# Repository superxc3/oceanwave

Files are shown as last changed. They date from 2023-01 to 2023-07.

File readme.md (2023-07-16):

# Oceanwave


Oceanwave is an ergonomic unibody keyboard with 3x6 column staggered keys and 3 thumb keys designed by XCMKB. Oceanwave was inspired by [Reviung41](https://github.com/gtips/reviung/tree/master/reviung41) and [Corne](https://github.com/foostan/crkbd) additional thumb key, splayed [Architeuthis Dux](https://github.com/tapioki/cephalopoda/tree/main/Architeuthis%20dux) with mx spacing. 

## Features
1. Hotswap for MX and Low Profile Choc (v1)
2. 8 RGB LED underglow 
3. 1 MX hotswap in the middle for Artisan. 
4. 1 flat wheel encoder
5. 1 EC11 / EC12 rotary encoder
6. 1 OLED
7. Pimoroni Haptic BZZZ DRV2605L Linear Actuator Haptic Breakout
8. Firmware supports wired VIAL and wireless ZMK
9. Modification of promicro or nicenano v2 for additional IOs. 
10. Power button for wireless build

## Versions
Supports multiple options of featuers for default micro controller
| Version | Features | Firmware | Wired | Wireless |
|:---|:---|:--:|:--:|:--:|
| Wirelss minimal | Flat wheel and knob | ZMK | | Yes |
| 2E | Flat wheel and knob | QMK/VIAL | Yes ||
| Oled 1E | Flat wheel or knob, Oled | QMK/VIAL | Yes ||
| Haptic 1E | Flat wheel or knob, Haptic BZZZ | QMK/VIAL | Yes ||

IO can be expanded by modifying the usb c promicro, inspired from [GOLEM](https://golem.hu/guide/pro-micro-upgrade/).
| Version | Features | Firmware | Wired | Wireless |
|:---|:---|:--:|:--:|:--:|
| Oled 2E* | Flat wheel and knob, Oled | QMK/VIAL | Yes ||
| Haptic 2E* | Flat wheel and knob, Haptic BZZZ | QMK/VIAL | Yes ||


Haptic Bzzz can always be added. Dang for the socketed haptic bzzz as well. 

## Build guide
[Refer here](https://github.com/superxc3/oceanwave/blob/main/build%20guide.md).

## Firmware
[Refer here](https://github.com/superxc3/oceanwave/tree/main/firmware)

## EC11/EC12 Encoders
1. EC11 is the typical 15mm rotary encoder used for most of the mx boards, the height is almost similar to mt3. 
2. EC12 is a relatively lower height rotary encoder, used for choc board to achieve thin board thickness.  

## OLED
oled

## Keyboard Images






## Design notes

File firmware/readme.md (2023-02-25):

# Firmware
Pre-assembled board is pre-flashed. Build kit please refer to [Ready-to-flash](https://github.com/superxc3/oceanwave/tree/main/firmware/ready-to-flash-firmware). If you wish to improve the codes, you will have to set up VIAL environment.

For pre-assembled and pre-flashed board, please download [VIAL](https://get.vial.today/download/) software to remap key. The software supports windows, mac, and linux. Basic layering and tapping guide refer [here](https://github.com/superxc3/xcmkb/blob/main/list%20of%20guide/vial-guide.md#basic-tapping-and-layering).

||
|:--:|
|Vial software interface|

## Wired QMK VIAL
- For usb-c promicro using caterina, copy xcmkb/oceanwave folder, make using `qmk compile -kb xcmkb/oceanwave -km vial`
- For rp2040 promicro, copy [oceanwave](https://drive.google.com/drive/folders/15KPRZ52J217cfi-xYsaPOL3EPukIM2lr?usp=sharing) folder to your qmk directory, make using `qmk compile -kb oceanwave -km vialoh2e`. Default uf2 which enabled all features download from [here](https://drive.google.com/file/d/1fGqhYeTPkiZEdB_yfewdT_9bDBihB43H/view?usp=share_link). 

### Configuration on Sparkfun RP2040 promicro
- Haptic vibration refers to [DRV2605L waveform library](https://github.com/qmk/qmk_firmware/blob/master/docs/feature_haptic_feedback.md#drv2605l-waveform-library); layers and tab key are added in the firmware, the rest just follow the template set in `haptic.c`.

## Wireless ZMK
Copy [oceanwave](https://drive.google.com/drive/folders/1NOylumwA9jJXKU2bHk5CELzXyPIMklsh?usp=share_link) to shields, this supports zmk-ftc only. Make using `west build -p -b nice_nano_v2 -- -DSHIELD=oceanwave`. Default keymap using reviung41 by adding extra key near to thumb. Default uf2 copy from [here](https://drive.google.com/file/d/1I9lbSuJ4-EFsmNMYBPXVArRPtXQpIEmn/view?usp=share_link). 
- no oled
- two encoders (flat wheel and rotary encoder)
- rgb included
- no haptic bzzz

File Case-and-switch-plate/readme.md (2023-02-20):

# Case and Switch Plate

## 3D case for plateless build 
This is suitable for low profile choc version without any switch plate, download [here](https://github.com/superxc3/oceanwave/blob/main/Case-and-switch-plate/Flat%20oceanwave2%20only%20-%20final%20touch.stl). 



o

3D reduces the overall thickness by 1mm compared to acrylic bottom, gap between bottom case and pcb are 2mm for 3D and 3mm for acrylic bottom.
- m2 x3mm screw at bottom
- m3 x3mm brass standsoff
- plastic washer on top of pcb
- m2 x3mm screw on top of pcb

### MCU cover
- m2 x3mm screw at bottom pcb
- m3 x11mm brass standsoff
- m2 x3mm screw on top of mcu cover

## Acrylic bottom plate
The gap between bottom acrylic plate and pcb is 3mm.
- m2 x3mm screw at bottom
- m3 x3mm brass standsoff
- m2 x3mm screw on top of pcb

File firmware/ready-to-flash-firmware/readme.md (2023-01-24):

# Ready to flash firmware

## Hex for caterina promicro
Using QMK Toolbox and refer [Tutorial to flash hex file](https://github.com/superxc3/xcmkb/blob/main/list%20of%20guide/flashing%20hex.md)

## uf2 for rp2040 
Flash before soldering. Connect usb c to pc.
1. Hold the boot button on mcu, double press reset button twice. 
2. A new window pop out.
3. Drop the uf2 to the folder.
4. Done.

## Version

### Default features
- 7 layers (Layer 0123456)
- 1000Hz polling rate
- OLED/haptic depends on the build
- Mousekey availability depends on firmware size
- RGB underglow effects number depends on firmware size
- super alt tab enabled to cycle between different windows (check User tab in vial)



### Oled2e
This version for OLED, without Haptic Bzzz, supports both knob and flat wheel encoders. Hex file download [here](https://drive.google.com/file/d/1fGqhYeTPkiZEdB_yfewdT_9bDBihB43H/view?usp=share_link). QMK VIAL firmware source code download [here](https://drive.google.com/drive/folders/1AIHQoCwNvRf_bx6QMLS1yq8Js87rkkeG?usp=share_link). 

Copy XCMKB and compile using `qmk compile -kb xcmkb/oceanwave -km vialoled2e`. Default comes with OLED indicator for layer, numlock, capslock, scrollock. Change the build option in oled.c for QMK logo. Animated oceanwave logo needs debug. 

**Optional features**
- mousekey disabled to accommodate rgb underglow
- qmk settings, combo, tap dance are disabled

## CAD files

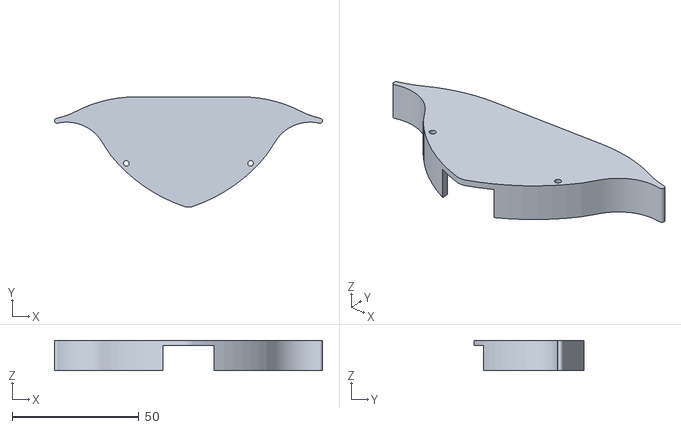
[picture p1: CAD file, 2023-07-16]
Case-and-switch-plate/mcu cover with 103040 1500mah battery.stl
105.9 x 43.6 x 12.0

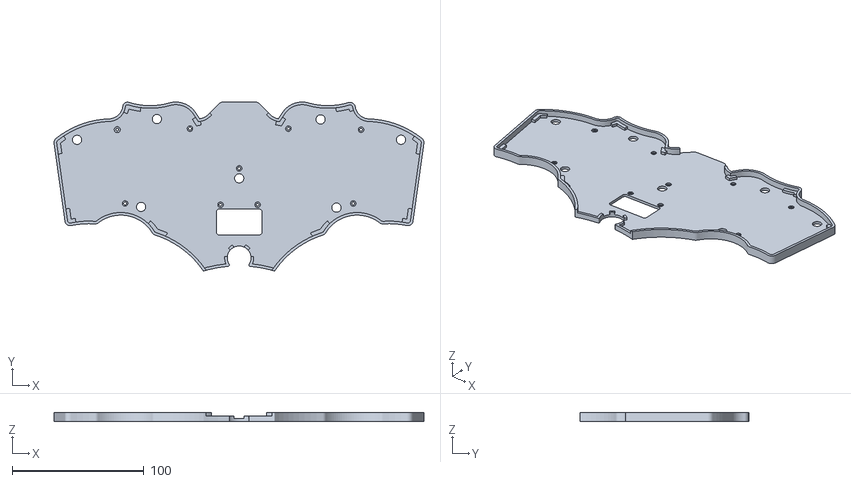
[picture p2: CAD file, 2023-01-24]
Case-and-switch-plate/Flat oceanwave2 only - final touch.stl
280.3 x 128.1 x 6.60

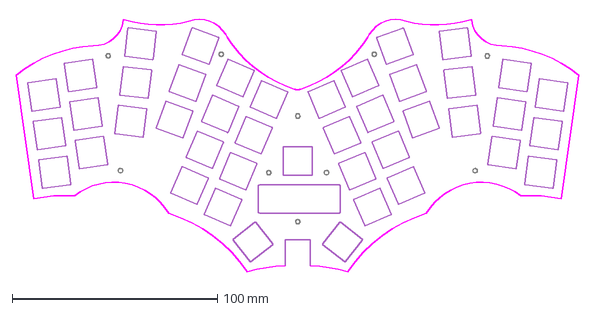
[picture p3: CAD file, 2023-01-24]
Case-and-switch-plate/Switch plate.dxf
274.1 x 124.4 mm

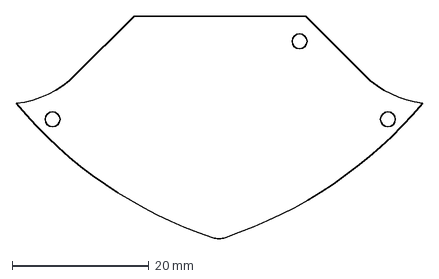
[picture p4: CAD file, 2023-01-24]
Case-and-switch-plate/MCU Cover.dxf
59.5 x 32.6 mm

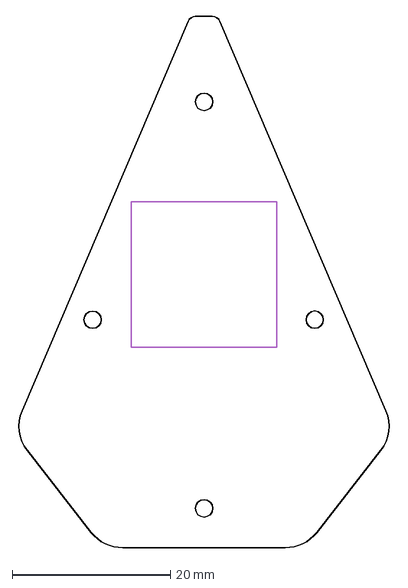
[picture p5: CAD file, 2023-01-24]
Case-and-switch-plate/Oled Cover.dxf
47.5 x 67.3 mm

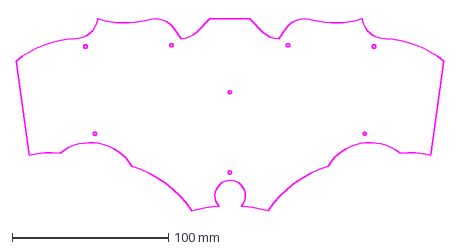
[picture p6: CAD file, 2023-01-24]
Case-and-switch-plate/Bottom Acrylic Plate without haptic.dxf
274.1 x 124.4 mm

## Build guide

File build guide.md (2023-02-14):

# Build Guide of Oceanwave

### Default combination
Due to limitation of IOs, not all features can be included (4. to 7.). Below shows the combination without modifying promicro / nicenano v2

1. 1 Flat Wheel Encoder + OLED  	(join split paste for OLED on top of PCB)
2. 1 Flat Wheel Encoder + BZZZ  	(join split paste for BZZZ on top of PCB)
2. 2 Encoders, no OLED and BZZZ 	(join split paste above the flat wheel on top of PCB)

:warning: Notes

1. If do not want flat wheel as first encoder and choose ec11 rotary encoder knob, join split paste at the bottom of PCB written "JOIN IF OMIT FLAT WHEEL"
2. Once flat wheel is soldered, it must be used.
3. DO NOT SIMPLY JOIN ANYTHING IF YOU DONT USE THAT FEATURE

### Additional combination
Below shows possible combination by jump wire certain spots for additional IOs.

#### 2 Encoders + OLED or BZZZ
1. Join the ENCC and D on top of mcu (bridge wire between IO and both points)
2. Do not join split paste above the flat wheel
3. Join split paste of OLED or BZZZ depends on your choice, do not join both.

:warning: Below will lead to conflict if
1. Join OLED or BZZZ and join split paste above the flat wheel
2. Join both OLED and BZZZ

## Basic build guide

### Diodes
There are two types of diodes for oceanwave. The top facing upwards is through-hole diode; while the bottom is using SMD diode. You have to solder both types of diodes. Follow the line indicated on the pcb. 

||
|:--:|
| Through-hole diode |

||
|:--:|
| SMD diode; refer to [DIODES](https://github.com/GEIGEIGEIST/KLOR/blob/main/docs/buildguide_3DP.md#diodes) for tips to solder SMD diode |

### MCU - Microcontroller and Reset Button
The build kit comes with socket for MCU. Solder the socket and reset button after diodes. Use tape to fix the socket and solder accordingly. Default comes with usb c promicro. 

||
|:--:|
|MCU and reset button |

||
|:--:|
| Insert the 3 pieces of 4pins at each side, put the mcu on top. Press while solder four sides of MCU, make sure no gap in between the mcu and pins. Continue to solder with the rest.|

### RGB Underglow
Apply some solder on one of the pads. Place the LED with tweezer according to the silk screen. Reheat the solder and apply some pressure with tweezer to make sure the LED is fully seated. There is an LED facing up in the middle for artisan purpose. Recommended not installed for OLED user (the led shines the oled component); and not recommended if you are not planning to insert any switch, it glares. 

||
|:--:|
|Indicator silk screen. The orientation is very important. |

### Switch Sockets
Apply some solder on one of the pads, then place the switch socket and reheat the solder. While heating, press the socket with finger or tweezer. Make sure the socket is fully seated, lift your soldering iron but make sure your finger or tweezer is still pressing the socket for 1-2s. Check if the socket is aligned, then only solder the second pad. Build guide for socket and refer to [Switch Sockets](https://github.com/GEIGEIGEIST/KLOR/blob/main/docs/buildguide_3DP.md#switch-sockets).

### Encoders

#### EC11 Knob only
If you only have one encoder and prefer ec11 knob rather than flat wheel, bridge the three jumpers near to L4 RGB underglow led, above flat wheel. 

||
|:--:|
| Join if omit flat wheel as the encoder|

||
|:--:|
|Top: EC12 encoder with lower height, suitable for low profile choc; |
|Bottom: EC11 encoder suitable for mx choc, the height of EC11 knob is similar to the the height of MT3 keycaps.|

  :warning: The EC11 encoder allows Mill-Max 0305. However, it appears to be less stable if using Mill-Max

#### EC11 Knob and Flat Wheel
If your configuration allows you to build two encoders (both flat wheel and ec11 knob), bridge the three jumpers above the knob.

  :rotating_light: Do not bridge three jumpers above the knob to enable the knob, bridge only if you have two encoders.

||
|:--:|
| Join if your config allows for two encoders|

#### EC11 Knob and Flat Wheel with Oled and Haptic Bzzz
All enabled by expanding IO for second encoder. 
||
|:--:|
| Join either one of the GND, top or bottom; the another two needs to be handwired |

### OLED and Haptic Bzzz
~~Choose only OLED or Haptic Bzzz. You are allowed to bridge one of them only because they shared the same pins.~~
OLED and Haptic Bzzz are both supported as long as your firmware can fit in. 
||
|:--:|
| Join the left 4 jumpers if choose for OLED; join the right 4 jumpers if choose for haptic bzzz. Socket for OLED on top; socket for haptic at the bottom. The photo above shows example of haptic bzzz|
||
| The pins are extracted to reduce the height for socketed haptic bzzz|
||
| Silk screen explains how you should orientate the haptic bzzz, eg. GND to GND|

### Assemble
Sequence from bottom: 
1. Longer m2^4 screw at the bottom of acrylic plate
2. Acrylic bottom plate
3. Brass standsoff
4. Plastic standsoff
5. PCB
6. Shorter m2^3 screw on top of pcb

|assemble|
|:--:|
| Screws and standsoff etc |
|Assemble - lp|
| Low profile choc assemble without switch plate |
|mx assemble|
| MX assemble with switch plate and oled instruction |

## Credits
Thanks for bek_jerm for pointing on knob build guide issue.

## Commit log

2023-02-05 Recommended not to install facing up led
2023-02-20 3d case explanation
2023-07-16 Added new mcu cover stl file
    This is suitable for 103040 with 1500mah battery. Not tested yet.
    Intention: battery drops fast when niceview is installed, need to charge in one to two days, hence adding more battery capacity.
    [mcu cover with 103040 1500mah battery.stl]
